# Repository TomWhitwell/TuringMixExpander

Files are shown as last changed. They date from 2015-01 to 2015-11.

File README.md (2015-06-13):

##Turing Vactrol Mix Expander   

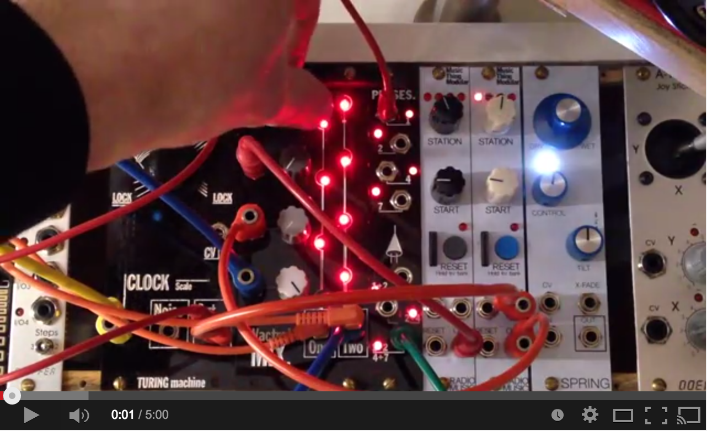
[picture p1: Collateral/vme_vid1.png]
[](http://youtu.be/Ccwjb2riCqE)
  

- A 4 in, 2 out  vactrol matrix mixer controlled by the Turing Machine  
- Connects to the Gates output, can be daisychained with Voltages  
- Creates rhythmic patterns or shifting drones from any audio source 
- Great for feedback loops  
- DC coupled, so you can also rhythmically cut up DC sources; LFOs etc. 
- Inspired by Grant Richter's Cadavre Exquis voltage controlled mixer.  
- NB: Fully expanded Turing (Pulses, Voltages, Vactrol) draws up to 190mA of current, so you may need to upgrade (or short circuit) the polyfuses in your backpack. 

###Resources  

[Documentation](https://github.com/TomWhitwell/TuringMixExpander/wiki)   
[Patch Ideas](https://github.com/TomWhitwell/TuringMixExpander/wiki/Patch-Recipes)  
[Manual](https://github.com/TomWhitwell/TuringMixExpander/wiki/How-to-use-the-module)  
[Issue Log](https://github.com/TomWhitwell/TuringMixExpander/issues)   
[Schematic](https://github.com/TomWhitwell/TuringMixExpander/wiki/Schematics)  

There is no PCB Panel layout, but there is a prototype lasercut panel in the hardware folder.  

###Demos: 
[Video 1: General demo](http://youtu.be/Ccwjb2riCqE)  
[Video 2](http://youtu.be/xf4IhIy3am4)  
[Video 3](http://youtu.be/hwUs_kbf3PM)  
[Vactrol Mix Expander 1](https://soundcloud.com/musicthing/random-looping-vactrol-mixer)  
[Vactrol Mix Expander 2](https://soundcloud.com/musicthing/exquisite-corpse-2)  
[20 Minutes of Madness](https://soundcloud.com/musicthing/radio-music-20-minutes-of-madness)  

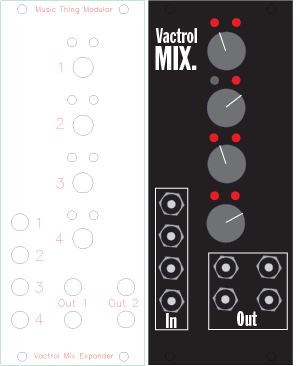
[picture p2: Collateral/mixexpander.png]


Turing Machine Vactrol Mix Expander  

This module design is Creative Commons Licensed by Tom Whitwell: CC-BY-SA

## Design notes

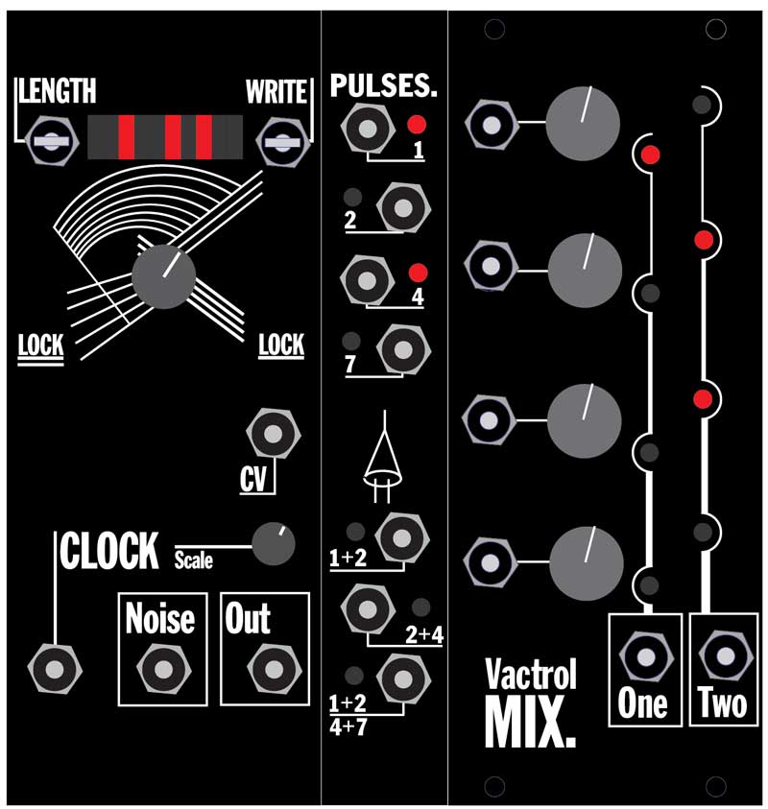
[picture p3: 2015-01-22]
Collateral/random_seq_panels+VISUAL-01.jpg

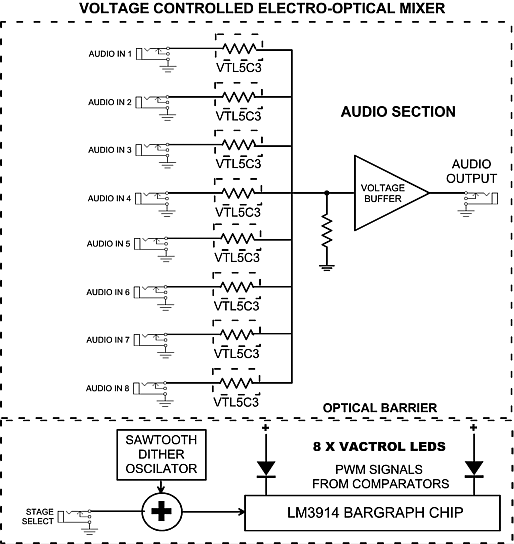
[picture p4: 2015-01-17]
Collateral/CORPSEdiagram1.GIF

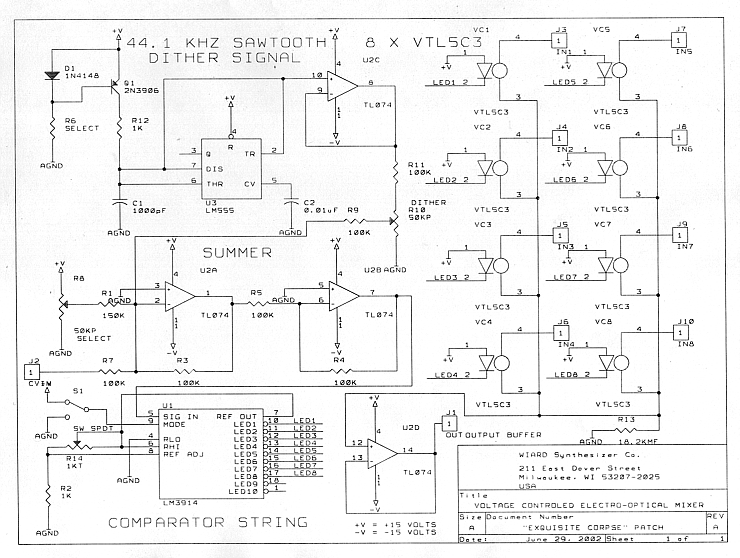
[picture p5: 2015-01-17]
Collateral/VCEOM2.GIF

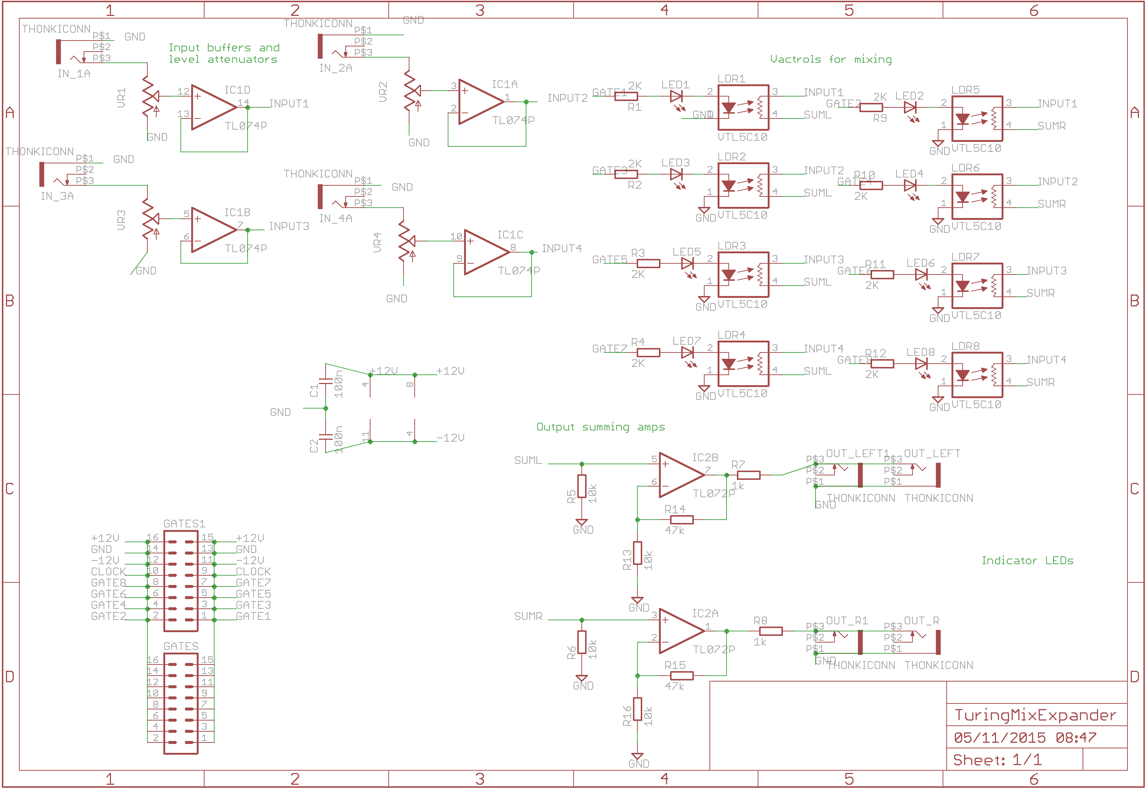
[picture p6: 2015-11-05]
Collateral/TuringMixExpander.png

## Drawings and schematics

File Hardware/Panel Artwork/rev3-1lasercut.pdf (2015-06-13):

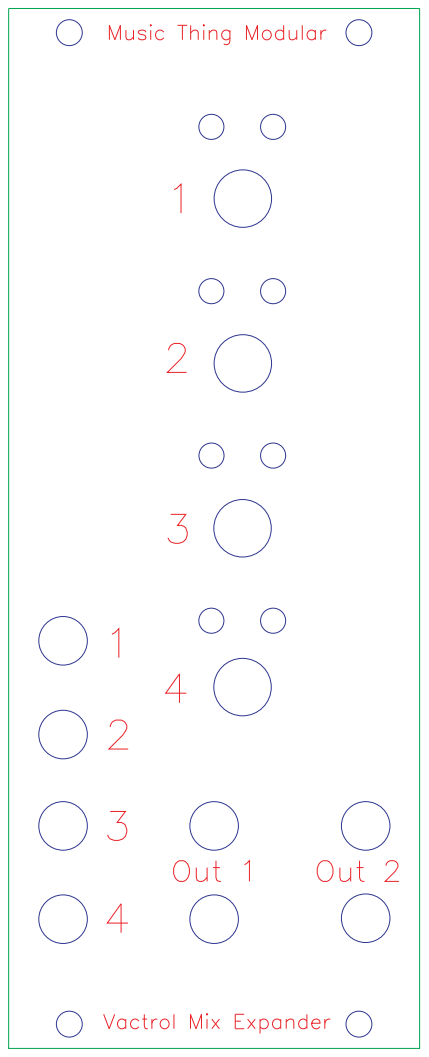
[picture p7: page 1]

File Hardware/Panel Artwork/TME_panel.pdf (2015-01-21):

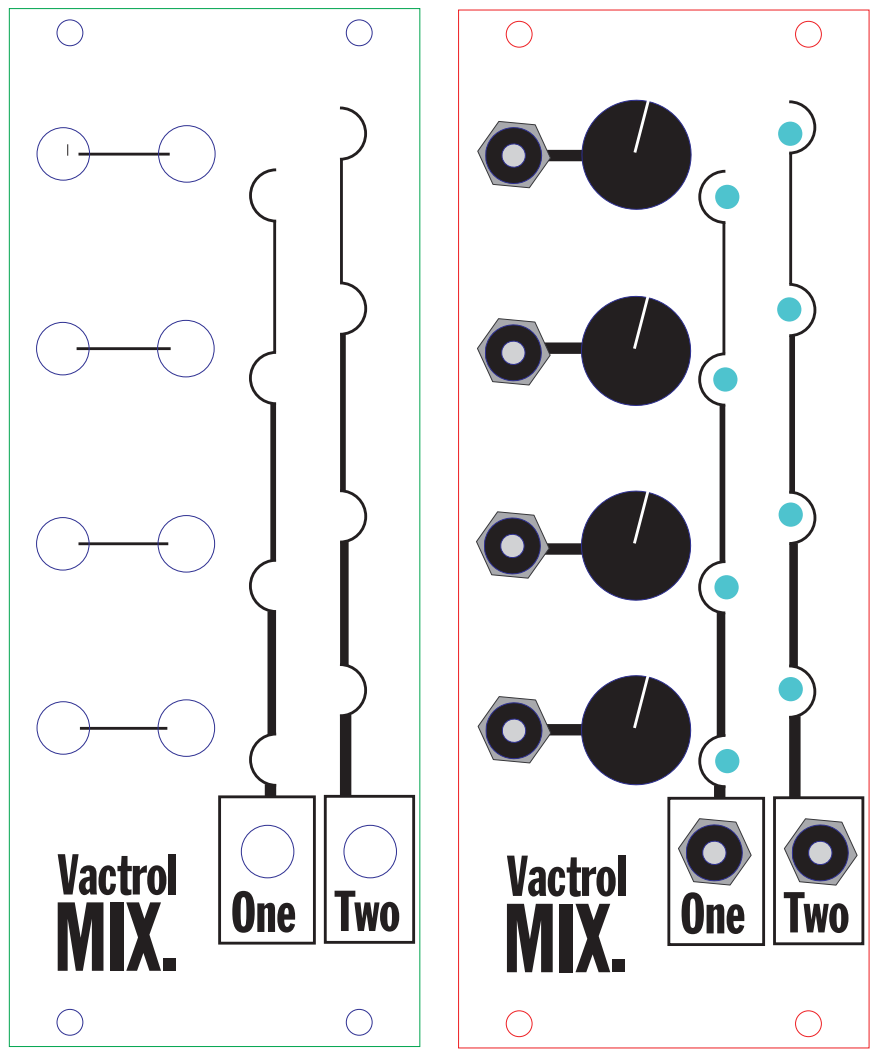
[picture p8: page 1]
ctrol

ctrol One Two MIX.

One Two MIX.

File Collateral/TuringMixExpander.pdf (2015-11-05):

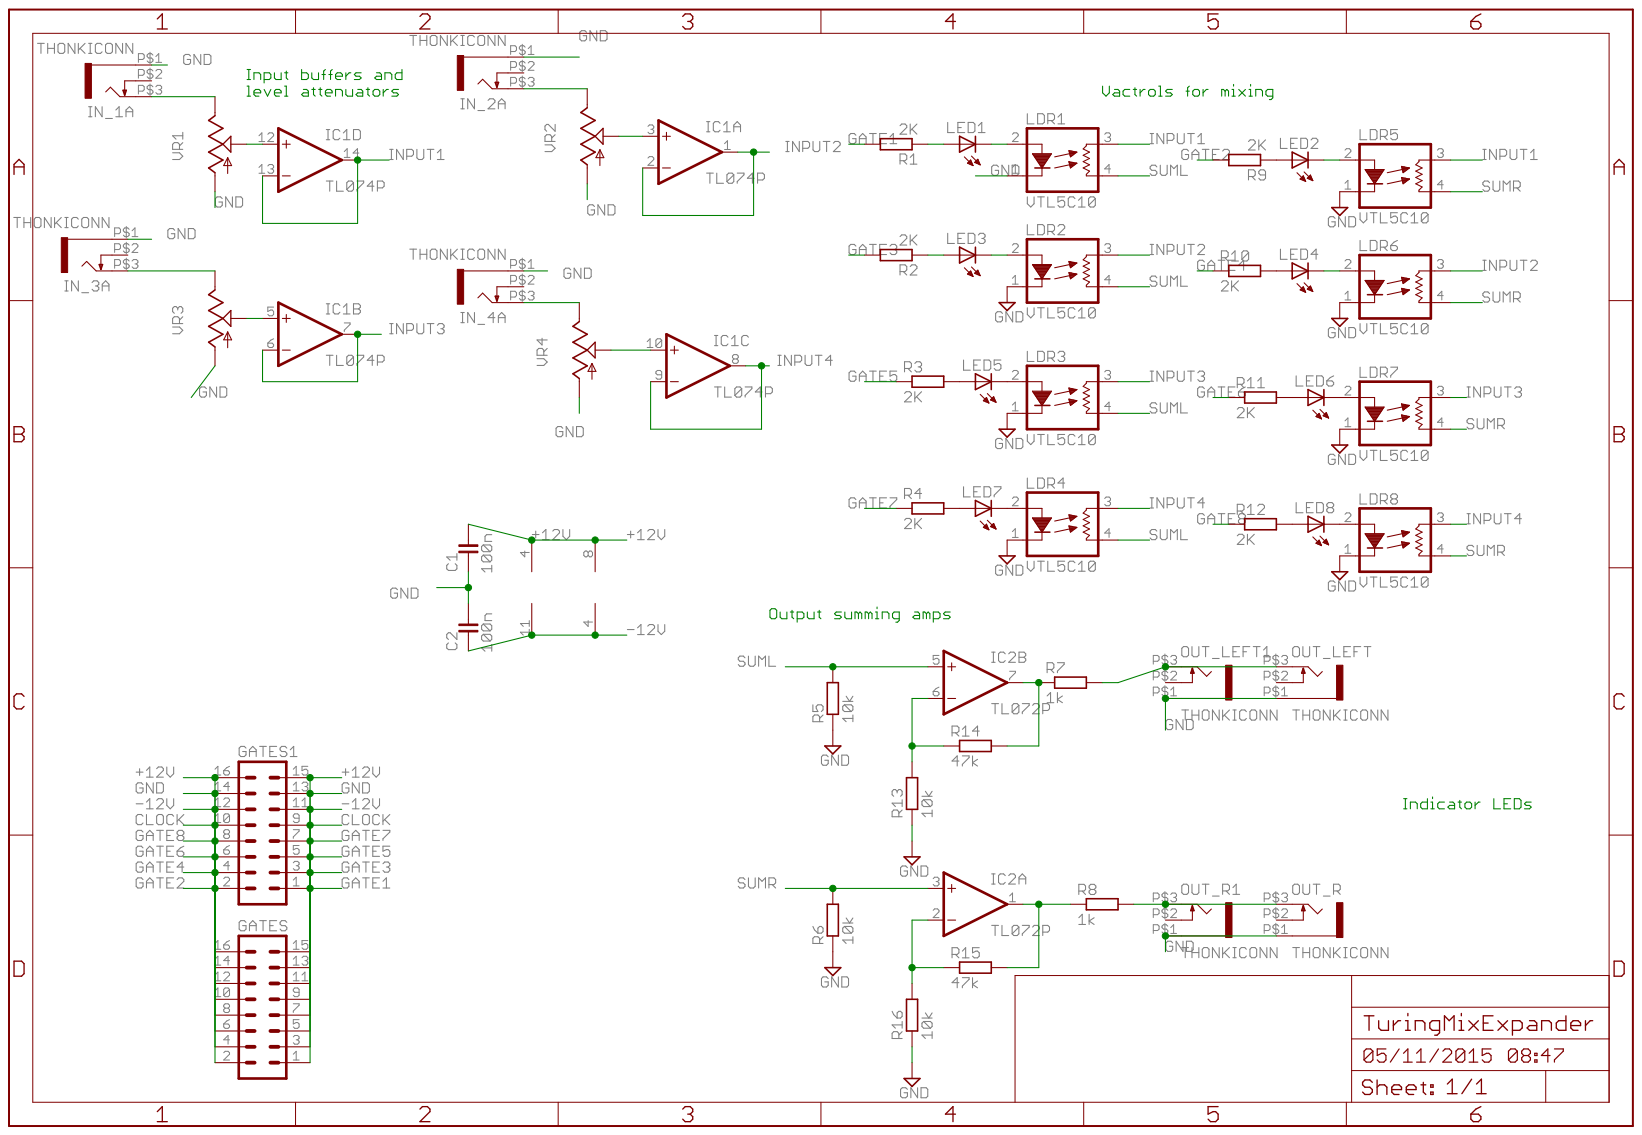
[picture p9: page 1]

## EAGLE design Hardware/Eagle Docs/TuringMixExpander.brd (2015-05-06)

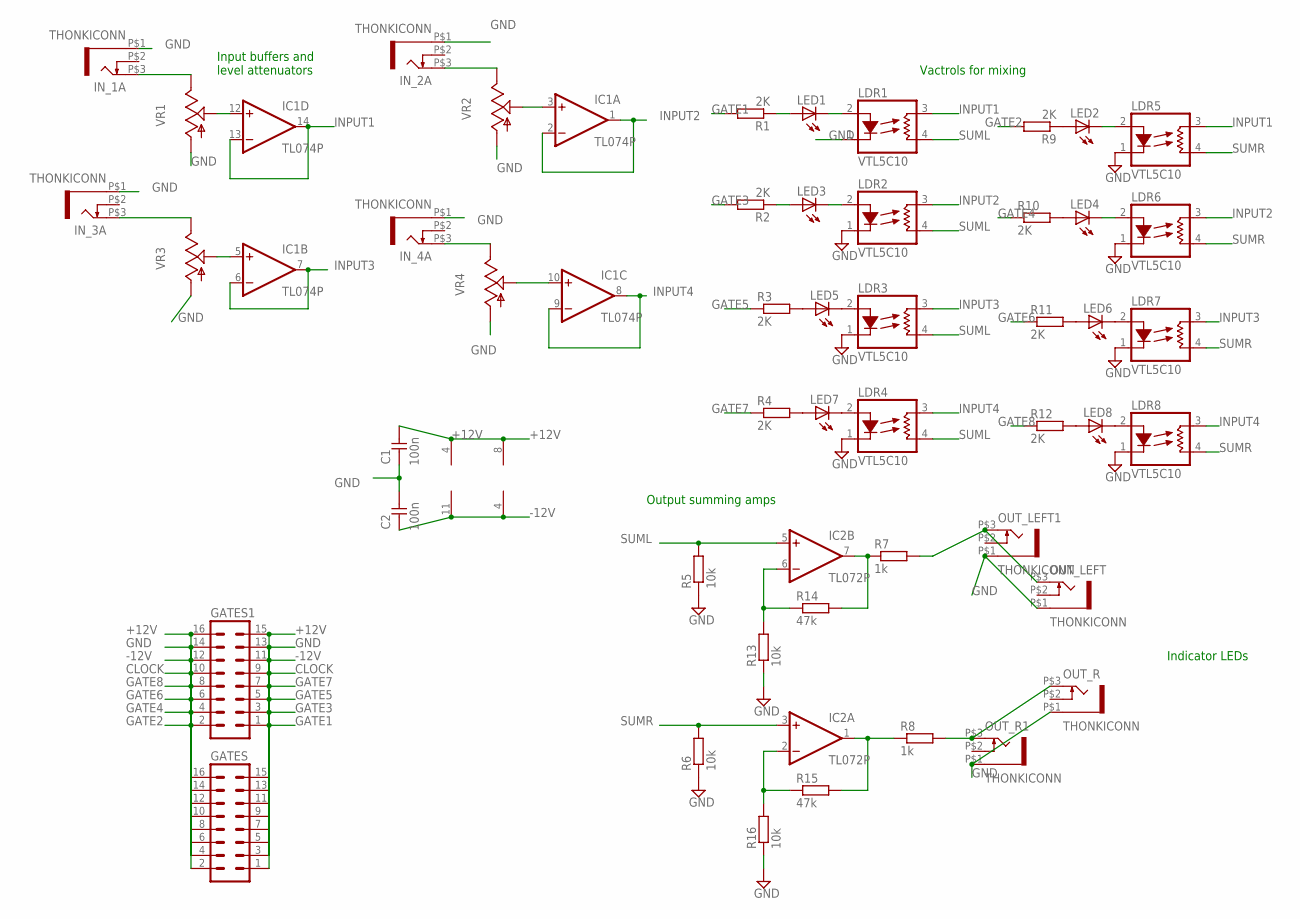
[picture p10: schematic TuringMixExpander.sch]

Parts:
C1, C2: 100n; C050-024X044
GATES, GATES1: MA08-2
IC1: TL074P; DIL14
IC2: TL072P; DIL08
IN_1A, IN_2A, IN_3A, IN_4A: THONKICONN
LDR1, LDR2, LDR3, LDR4, LDR5, LDR6, LDR7, LDR8: VTL5C10; VTL5C
LED1, LED2, LED3, LED4, LED5, LED6, LED7, LED8: LED3MM
OUT_LEFT, OUT_LEFT1: THONKICONN
OUT_R, OUT_R1: THONKICONN
R1, R2, R3, R4, R9, R10, R11, R12: 2K; 0207/7
R5, R6, R13, R16: 10k; 0207/7
R7, R8: 1k; 0207/7
R14, R15: 47k; 0207/7
VR1, VR2, VR3, VR4: ALPHA-9MMF2A; EVUF

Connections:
+12V: C1.1, GATES.15, GATES.16, GATES1.15, GATES1.16, IC1.4 (V+), IC2.8 (V+)
-12V: C2.2, GATES.11, GATES.12, GATES1.11, GATES1.12, IC1.11 (V-), IC2.4 (V-)
CLOCK: GATES.9, GATES.10, GATES1.9, GATES1.10
GATE1: GATES.1, GATES1.1, R1.2
GATE2: GATES.2, GATES1.2, R9.2
GATE3: GATES.3, GATES1.3, R2.2
GATE4: GATES.4, GATES1.4, R10.1
GATE5: GATES.5, GATES1.5, R3.1
GATE6: GATES.6, GATES1.6, R11.1
GATE7: GATES.7, GATES1.7, R4.1
GATE8: GATES.8, GATES1.8, R12.1
GND: C1.2, C2.1, GATES.13, GATES.14, GATES1.13, GATES1.14, IN_1A.P$1 (5), IN_2A.P$1 (5), IN_3A.P$1 (5), IN_4A.P$1 (5), LDR1.1 (LED-), LDR2.1 (LED-), LDR3.1 (LED-), LDR4.1 (LED-), LDR5.1 (LED-), LDR6.1 (LED-), LDR7.1 (LED-), LDR8.1 (LED-), OUT_LEFT.P$1 (5), OUT_LEFT1.P$1 (5), OUT_R.P$1 (5), OUT_R1.P$1 (5), R5.1, R6.1, R13.1, R16.1, VR1.1 (A), VR2.1 (A), VR3.1 (A), VR4.1 (A)
INPUT1: IC1.13 (-IN), IC1.14 (OUT), LDR1.3 (RES1), LDR5.3 (RES1)
INPUT2: IC1.1 (OUT), IC1.2 (-IN), LDR2.3 (RES1), LDR6.3 (RES1)
INPUT3: IC1.6 (-IN), IC1.7 (OUT), LDR3.3 (RES1), LDR7.3 (RES1)
INPUT4: IC1.8 (OUT), IC1.9 (-IN), LDR4.3 (RES1), LDR8.3 (RES1)
unnamed: IN_1A.P$3 (3), VR1.3 (E)
unnamed: IC1.12 (+IN), VR1.2 (S)
unnamed: IN_2A.P$3 (3), VR2.3 (E)
unnamed: IC1.3 (+IN), VR2.2 (S)
unnamed: IC2.7 (OUT), R7.1, R14.2
unnamed: OUT_R.P$3 (3), OUT_R1.P$3 (3), R8.2
unnamed: IC2.6 (-IN), R13.2, R14.1
unnamed: IC2.2 (-IN), R15.1, R16.2
unnamed: IC1.5 (+IN), VR3.2 (S)
unnamed: IN_3A.P$3 (3), VR3.3 (E)
unnamed: IN_4A.P$3 (3), VR4.3 (E)
unnamed: LDR1.2 (LED+), LED1.K (C)
unnamed: LDR2.2 (LED+), LED3.K (C)
unnamed: LDR3.2 (LED+), LED5.K (C)
unnamed: LDR4.2 (LED+), LED7.K (C)
unnamed: LDR5.2 (LED+), LED2.K (C)
unnamed: LDR6.2 (LED+), LED4.K (C)
unnamed: LDR7.2 (LED+), LED6.K (C)
unnamed: LDR8.2 (LED+), LED8.K (C)
unnamed: OUT_LEFT.P$3 (3), OUT_LEFT1.P$3 (3), R7.2
unnamed: IC1.10 (+IN), VR4.2 (S)
unnamed: IC2.1 (OUT), R8.1, R15.2
unnamed: LED1.A, R1.1
unnamed: LED3.A, R2.1
unnamed: LED5.A, R3.2
unnamed: LED7.A, R4.2
unnamed: LED2.A, R9.1
unnamed: LED4.A, R10.2
unnamed: LED6.A, R11.2
unnamed: LED8.A, R12.2
SUML: IC2.5 (+IN), LDR1.4 (RES2), LDR2.4 (RES2), LDR3.4 (RES2), LDR4.4 (RES2), R5.2
SUMR: IC2.3 (+IN), LDR5.4 (RES2), LDR6.4 (RES2), LDR7.4 (RES2), LDR8.4 (RES2), R6.2

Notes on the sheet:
Input buffers and level attenuators
Vactrols for mixing
Indicator LEDs
Output summing amps

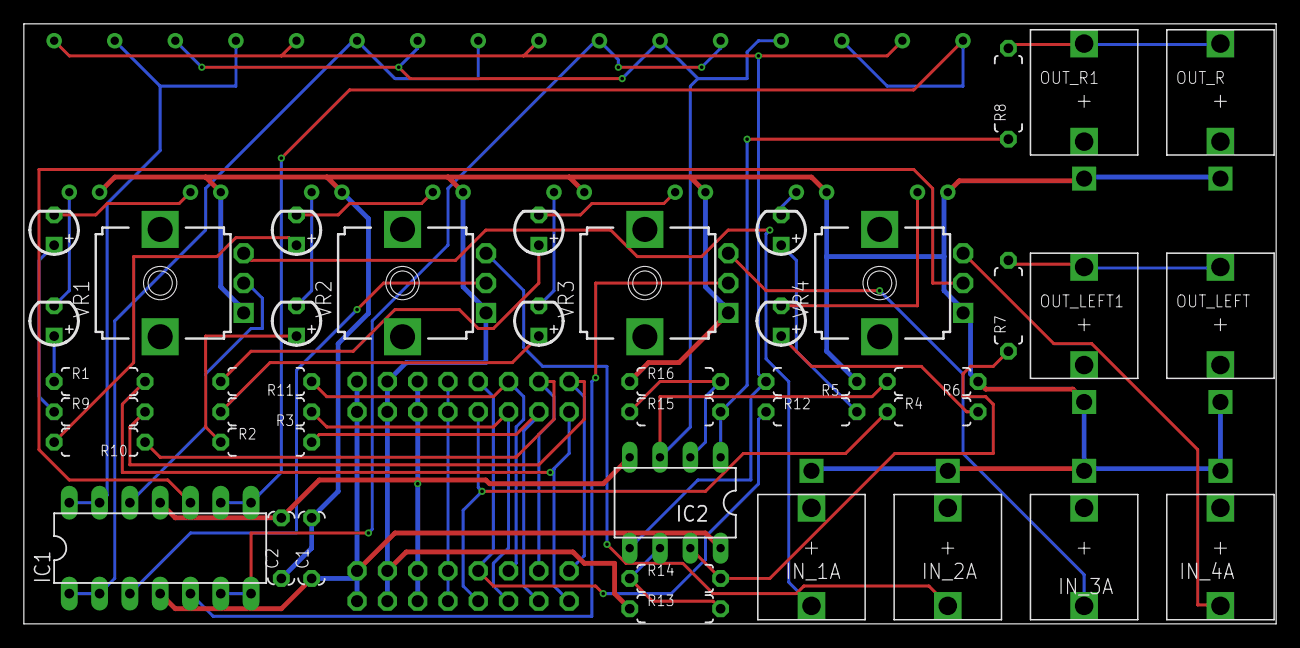
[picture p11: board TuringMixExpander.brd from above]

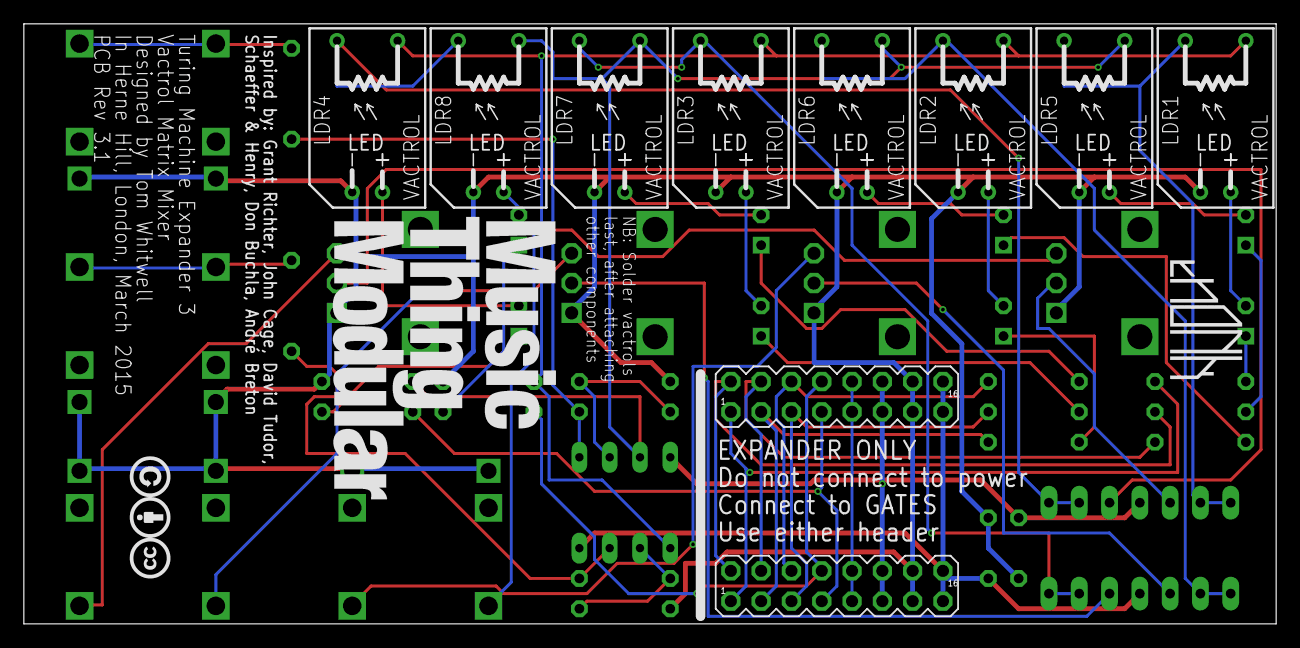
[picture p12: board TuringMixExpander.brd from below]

Board: 4 copper layers, 105.0 x 50.3 mm, 53 parts (13 on the bottom side), 48 nets.

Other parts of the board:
U$1: MTM_2CM
U$2: CC_1CM_SCREENPRINT
U$3: THONK_1CM_SCREENPRINT

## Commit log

2014-11-15 Upload working files
    [TuringMixExpander.brd, TuringMixExpander.sch]
2015-01-21 Add schematic
2015-01-21 add schematic image
2015-02-05 New pcb layout
    Added passthrough header
    Removed resistor networks
    Simplified led/resistor structure (one per channel, not two)
    New panel layout
    [TuringMixExpander.brd, TuringMixExpander.sch]
2015-02-12 New resistor grid
    [TuringMixExpander.brd, TuringMixExpander.sch]
2015-02-13 PCB work
    [TuringMixExpander.brd, TuringMixExpander.sch]
2015-03-13 Gerbers manufactured OSHPark
    [TuringMixExpander.GBL, TuringMixExpander.GBO, TuringMixExpander.GBP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]
2015-03-18 Rev 3.1 Gerbers for OSH Park
    [TuringMixExpander.brd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]
2015-06-13 Prototype Lasercut Panel Artwork
2015-11-05 Image upload, some schematic tidying
    [TuringMixExpander.sch]
